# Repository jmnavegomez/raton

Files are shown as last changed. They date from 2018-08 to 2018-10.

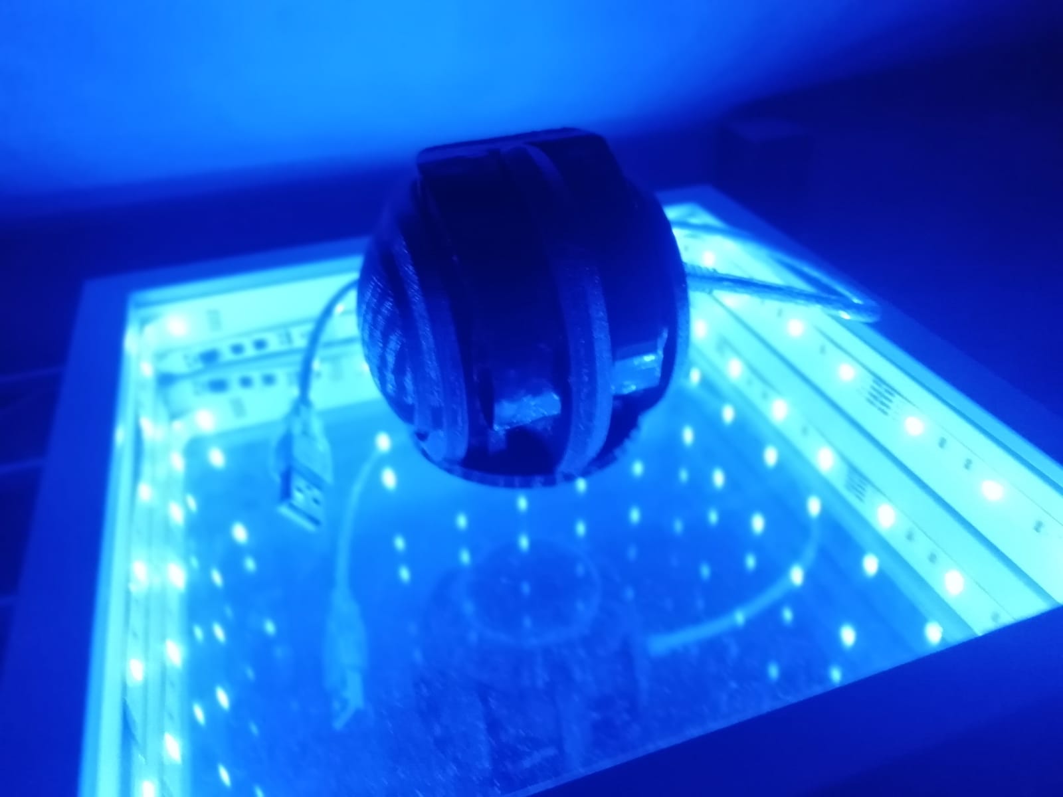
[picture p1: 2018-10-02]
Modelo 3D/Raton.jpeg

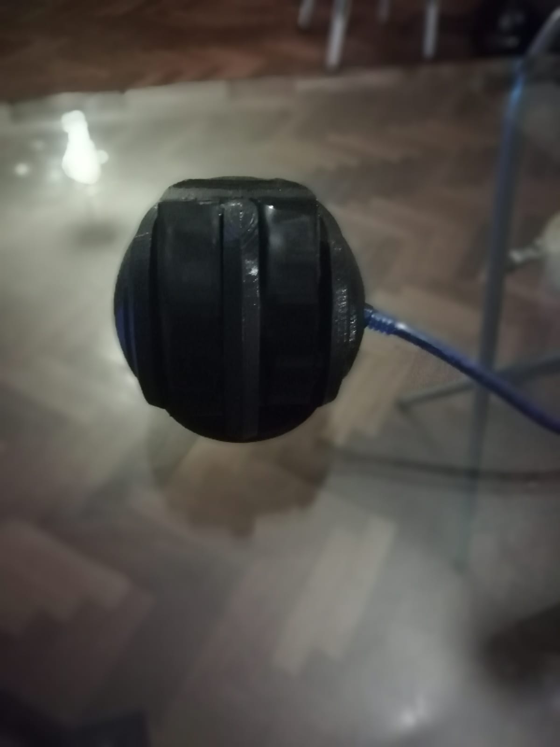
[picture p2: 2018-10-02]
Modelo 3D/WhatsApp Image 2018-10-02 at 22.29.49.jpeg

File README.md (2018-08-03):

# raton
Raton Libre y abierto que funciona con acelerómetro

## Software necesario
* Freecad [Pagina principal Freecad](https://www.freecadweb.org/)
* Arduino [Pagina descarga IDE Arduino](https://www.arduino.cc/en/Main/Software)

## Instalación
* Descargar el archivo de arduino raton.ino
* Abrirlo en el IDE de Arduino
* Subirlo a la placa (funciona con promicro y Leonardo)

## Hardware
* ADXL345
* Arduino promicro
* Dos pulsadores
* Cables
* Carcasa(Opcional)[Puedes imprimir la que se adjunta en modelo 3D]

## Recomendaciones
* Mirar los pines de SDA y SCL de la promicro (suelen ser la 2 y 3)
* Se conectan tres tierras: una al sensor y dos a los pulsadores
* Para conectar todo en la carcasa es necesario usar estañador con los pulsadores puestos, cuidado con no quemar el plástico
* Los pulsadores deben conectarse a tierra y a las salidas 4 y 5 (boton izquierdo y derecho respectivamente)
* Asegúrate de que los pulsadores no dejan pasar la corriente si no están pulsados (con un voltímetro)

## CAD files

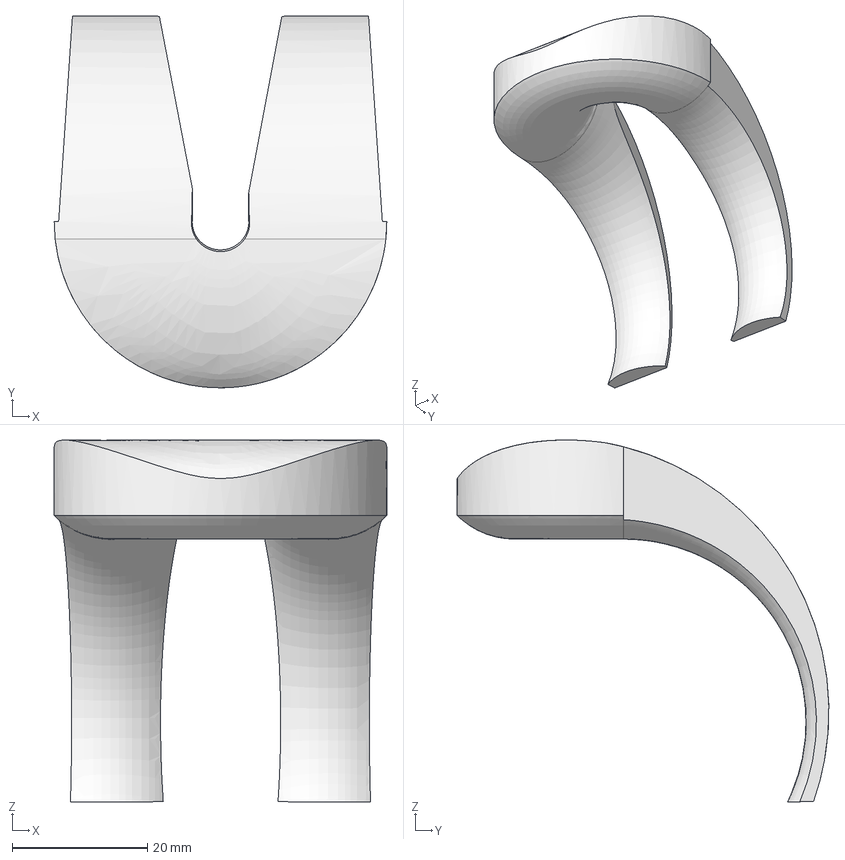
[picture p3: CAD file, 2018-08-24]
Modelo 3D/embellecedor.FCStd
49.2 x 55.0 x 53.6 mm

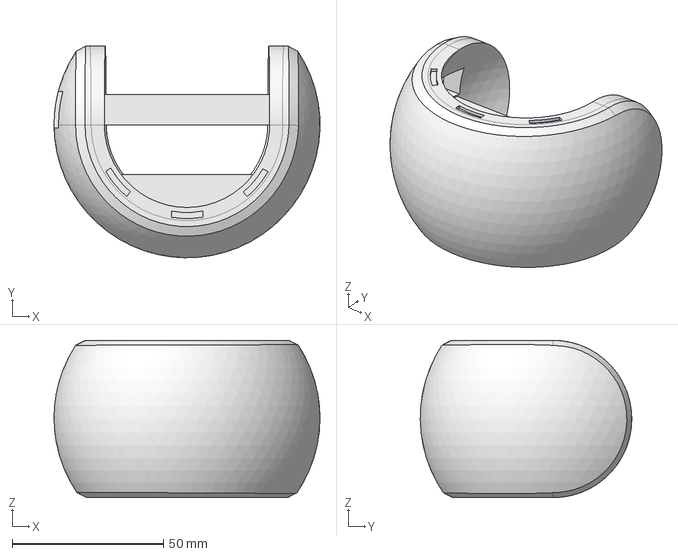
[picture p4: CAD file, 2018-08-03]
Modelo 3D/mouseesf2.FCStd
88.0 x 70.0 x 52.0 mm

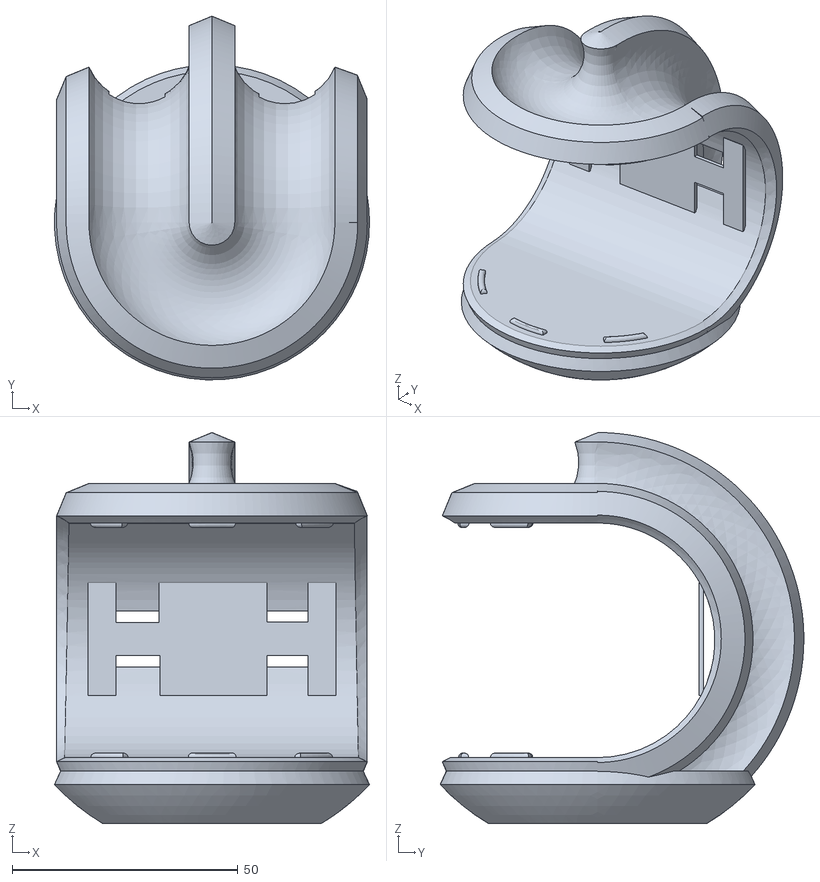
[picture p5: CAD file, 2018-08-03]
Modelo 3D/soporte.stl
69.8 x 80.6 x 86.7

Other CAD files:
Modelo 3D/esfera2.stl
Modelo 3D/mouse2.FCStd
Modelo 3D/Embellecedor.stl

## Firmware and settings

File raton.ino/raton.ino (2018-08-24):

/*raton
Copyright (C) 2018  Jose Manuel Naveiro

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
You should have received a copy of the GNU General Public License
along with this program.  If not, see <http://www.gnu.org/licenses/>.
*/

#include <Mouse.h>
#include <Wire.h>
#include <Adafruit_Sensor.h>
#include <Adafruit_ADXL345_U.h>
#include <Arduino.h>
int botonI=4;
int botonD=5;

/* Assign a unique ID to this sensor at the same time */
Adafruit_ADXL345_Unified accel = Adafruit_ADXL345_Unified(981152);
float X;
float Y;
float Z;
float ayud1;
float ayud2;
float ayud3=9.8;

void setup() {
  Mouse.begin();
  Serial.begin(9600);
  pinMode(botonI,INPUT_PULLUP);
  pinMode(botonD,INPUT_PULLUP);
  /* Initialise the sensor */
  if (!accel.begin())
  {
    /* There was a problem detecting the ADXL345 ... check your connections */
    Serial.println("Ooops, no ADXL345 detected ... Check your wiring!");
    while (1);
  }

  /* Set the range to whatever is appropriate for your project */
  //accel.setRange(ADXL345_RANGE_16_G);
  // displaySetRange(ADXL345_RANGE_8_G);
  // displaySetRange(ADXL345_RANGE_4_G);
  accel.setRange(ADXL345_RANGE_2_G);
  accel.setDataRate(ADXL345_DATARATE_400_HZ);
}

void loop(void) {
  int estadoBotonI=digitalRead(botonI);
  int estadoBotonD=digitalRead(botonD);
  Serial.println(estadoBotonI);
  if(estadoBotonI==0)
  {
    Serial.println("Apretando boton izq");
    Mouse.press(MOUSE_LEFT);  
  }
  else{
    Serial.println("Suelto boton izq");
    Mouse.release(MOUSE_LEFT);
  }
  if(estadoBotonD==0){
    Serial.println("Apretando boton DCho");
    Mouse.press(MOUSE_RIGHT);
  }
  else{
    Serial.println("Suelto boton DCho");
    Mouse.release(MOUSE_RIGHT);
  }
  /* Get a new sensor event */
  sensors_event_t event;
  accel.getEvent(&event);

  X = event.acceleration.x; /*Datos eje X*/
  Y = event.acceleration.y; /*Datos eje Y*/
  Z = event.acceleration.z; /*Datos eje Z*/

  /*Operaciones/tratamiento de datos */
  ayud1 = X/11;//(X / abs(X)) * sqrt(1 - pow(X / 11, 2));
  ayud2 = -Y/11;//(Y / abs(Y)) * sqrt(1 - pow(Y / 11, 2));
  ayud3 = Z;
  Serial.print(ayud1);
  Serial.println(ayud2);
  
  Mouse.move((int)(ayud1*10), (int)(ayud2*10)); /*Movimiento*/

  

  delay(4);
}

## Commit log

2018-08-03 primera edicion
    [esfera2.stl, mouse2.FCStd, mouseesf2.FCStd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]
2018-08-03 Puse que era con acelerómetro
2018-08-24 Cambio en el sentido de Y, con lo que es más intuitivo
2018-08-24 Embellecedor que sirve para cubrir la parte superior del mouse, sirve para facilitar el clicado
    [Embellecedor.stl, embellecedor.FCStd]

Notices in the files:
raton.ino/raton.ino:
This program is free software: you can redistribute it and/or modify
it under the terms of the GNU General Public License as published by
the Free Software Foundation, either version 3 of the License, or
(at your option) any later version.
